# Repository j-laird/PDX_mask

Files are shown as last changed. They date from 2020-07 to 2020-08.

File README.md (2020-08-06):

# PDX Refillable Mask Cartridge Project

## Disclaimer
Home-made respirator cartridges have plenty of safety concerns.  From the design - to materials used - to workmanship when re-assembling, there are risks to using this and other designs.  If you can find commercially built cartridges, please use them instead.  If you need to experiment?  Read on.  Not my pig, not my farm.

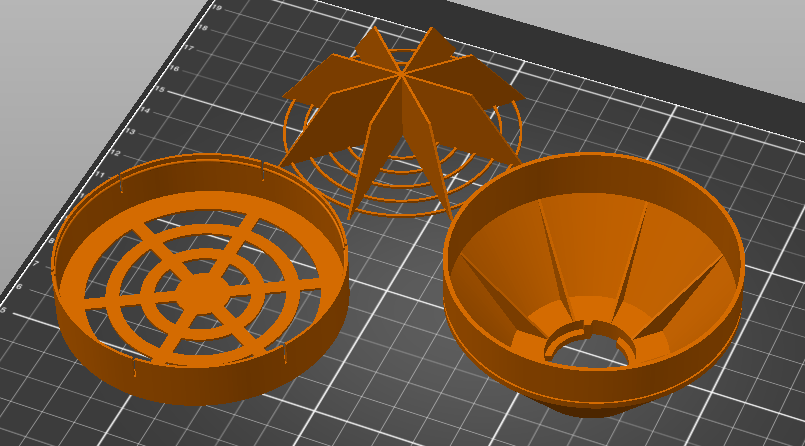
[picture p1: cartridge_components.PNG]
components


## Design Philosophy
- Not about me - my name is on it for questions, but if you can improve, please do.  
- Print Efficiency: Getting the most cartridges out to those in need is a priority
- Printability: This idea works only if different people with different printers can scale production
- Customization: OpenSCAD allows people to use free software to tweak design (improve print quality - account for variation in printer accuracy, etc)
- STLs for the People: Hopefully the default parameters make usable parts for most printers without having to load/edit design files

## Construction
Prototypes have been printed on a Prusa i3mk3 printer using PETG filament.  The design was optimized for print time, and takes advantage of the flexibility and durability of this material to snap together.  Total print time at 0.3mm layer height / draft quality is about 1h 45m per cartridge.  However:

- Cap and support can be printed at 0.3mm for speed
- Base prints good at 0.3mm now, but if you have poor surface, try 0.2mm. 

*new in v2 and later - cap has cap_fit_factor to grow/shrink for best fit.  

The design is implemented in 3 parts to provide better print quality with short print times.  A printed support is placed inside the bayonet base.  The user-side filter material will probably be cut and glued around the periphery, and the space is designed to support the use of activated carbon granules.  A second layer (environment side) can be glued to either the inside of the snap-on cap, or somehow glued to the top of the base.  Feedback welcome.

The height of the media (carbon) area is also parameteric if more/less is desired. 

## Customizing
Design implemented in OpenSCAD - Put all files in the same folder - most customization is in PDX_mask_dimensions.scad so that changes propogate to any affected parts.  

## Credits
Design leaned heavily on OpenSCAD 3M Bayonet adapter by james_lan: https://www.thingiverse.com/thing:4246959

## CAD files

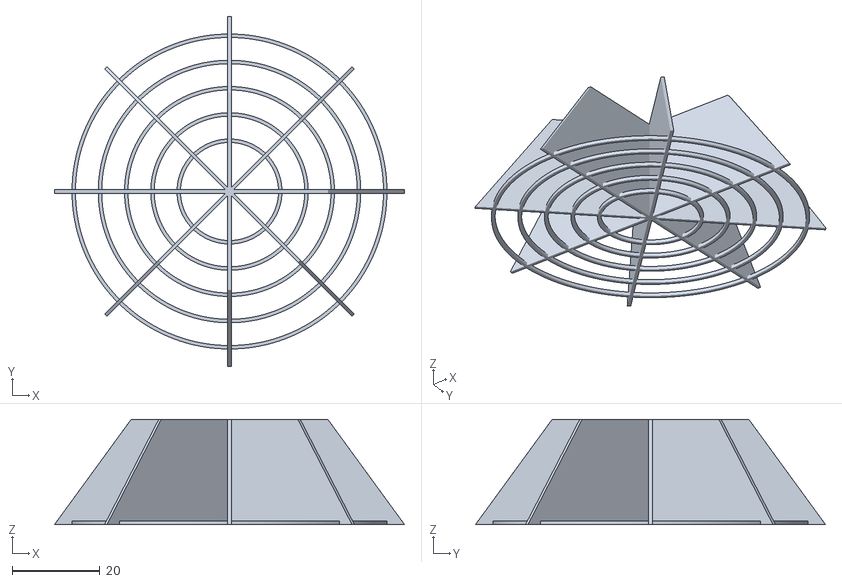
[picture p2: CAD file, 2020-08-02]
PDX_mask_support.stl
80.0 x 80.0 x 24.0

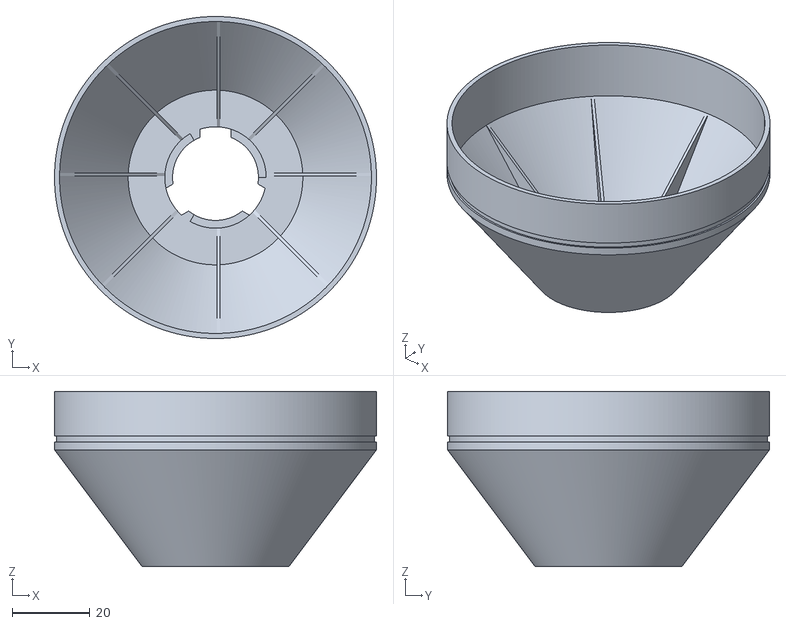
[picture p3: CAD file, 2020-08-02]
PDX_mask_base.stl
82.6 x 82.6 x 45.0

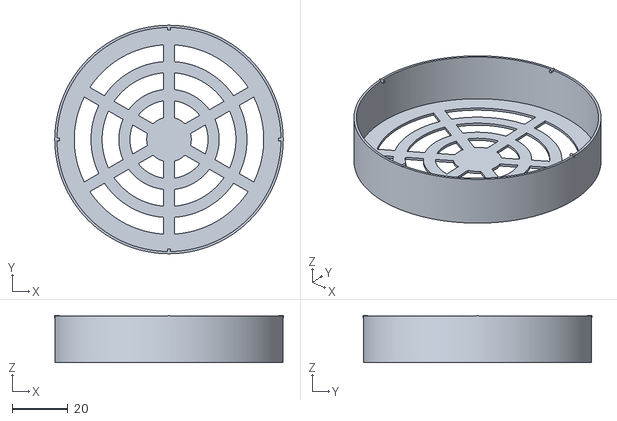
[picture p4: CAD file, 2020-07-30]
PDX_mask_cap.stl
82.2 x 82.2 x 17.0

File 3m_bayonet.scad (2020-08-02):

// source of this is https://www.thingiverse.com/thing:4246959
// with minor tweaks by @jesselaird

tolerance=0.5;
attachment_od=36;
attachment_height=6;
bayonet_od=21.5+tolerance;
bayonet_extra=2; //radius
bayonet_under=2.25;
bayonet_width=8;
bayonet_height=attachment_height-bayonet_under;
$fn=200;

module 3m_attachment() {
difference(){
	cylinder(r=attachment_od/2, h=attachment_height);
	cylinder(r=bayonet_od/2, h=attachment_height+2);
	for(i=[0:2]){
		rotate([0,0,120*i]){
            intersection(){
                cylinder(r=bayonet_od/2+bayonet_extra, h=attachment_height);
                translate([-bayonet_width/2, 0,0])
                cube([bayonet_width, attachment_od, attachment_height]);
            }
            translate([0,0,bayonet_under]) {
                intersection(){
                    cylinder(r=bayonet_od/2+bayonet_extra, h=bayonet_height);
                    translate([-bayonet_width/2, 0,0])
                    cube([bayonet_width*4, attachment_od, attachment_height]);
                }
            }
        }
	}
}
}

//To use:
// Put in same folder as 3m_bayonet.scad and in your file: 
//use <3m_bayonet.scad>
//3m_attachment();

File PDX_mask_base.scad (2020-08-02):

// PDX mask project base
// initial by Jesse Laird
// github j-laird; twitter @jesselaird

include <3m_bayonet.scad>
include <PDX_mask_dimensions.scad>

base_mount_inner_radius = attachment_od/2;
base_mount_outer_radius = base_mount_inner_radius + base_wall_thickness;
base_fin_width = 0.8;
base_rib_corner_radius = ((base_filter_inner_radius - base_mount_inner_radius) * 
                    (attachment_height / base_cone_height)
                    + base_mount_inner_radius + 0.1);

union(){
    // bayonet mount 
    3m_attachment();
    // cone transition between mount base and filter
    difference(){
        cylinder(h=base_cone_height,
                 r1=base_mount_outer_radius, 
                 r2=base_filter_outer_radius);
        cylinder(h=base_cone_height,
                 r1=base_mount_inner_radius, 
                 r2=base_filter_inner_radius);
    }
    // support between mount and cone:
    difference(){
        // Had to add fudge factor 0.1 to calculation to keep base manifold -JL
        cylinder(h=attachment_height,
                 r1=base_mount_inner_radius,
                 r2=base_rib_corner_radius);
        cylinder(h=attachment_height,
                 r=base_mount_inner_radius);
    }
    // interior ribs for reinforcement:
    difference(){
        intersection(){
            cylinder(h=base_cone_height,
                     r1=base_mount_inner_radius,
                     r2=base_filter_inner_radius);
            for(rot_deg = [0:45:135]){
                rotate([0,0,rot_deg]){
                    translate([base_fin_width/2, 
                               -1 * base_filter_inner_radius,
                               attachment_height]){
                        cube([base_fin_width, 
                              base_filter_inner_radius * 2, 
                              base_cone_height - attachment_height]);
                    }
                }
            }
        }
        translate([0,0,attachment_height]){
            cylinder(h=base_cone_height - attachment_height,
                     r1 = bayonet_od/2 + bayonet_extra,
                     r2 = base_filter_inner_radius);
        }
    }
    // filter area:
    translate([0,0,30]){
        difference(){
            // basic hollow cylinder:
            cylinder(h=base_filter_height,r=base_filter_outer_radius);
            cylinder(h=base_filter_height,r=base_filter_inner_radius);
            // now we'll remove a grove on the outside, 2mm up from where cone meets the filter area
            // - this forms a retention grove that interlocks a feature on the cap
            translate([0,0,retention_groove_offset]){
                difference(){
                    cylinder(h=retention_groove_height,
                             r=base_filter_outer_radius);
                    cylinder(h=retention_groove_height,
                             r=base_filter_outer_radius - retention_groove_depth); 
                }
            }
        }
    }
}

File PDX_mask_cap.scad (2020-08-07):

// PDX mask project - vent cap
// initial by Jesse Laird
// github j-laird; twitter @jesselaird

include <PDX_mask_dimensions.scad>

cap_inner_radius = cap_fit_factor * base_filter_outer_radius;
cap_outer_radius = cap_inner_radius + cap_wall_thickness;
cap_height_total_inner = base_filter_height;
cap_height_total_outer = base_filter_height + cap_thickness;

module cap_vent(){
    difference(){
        //circular vent features:
        union(){
            for(i=[2*cap_vent_thickness:5*cap_vent_thickness:cap_inner_radius]){
                difference(){
                    cylinder(h=cap_thickness*1.1, r=i);
                    cylinder(h=cap_thickness*1.2, r=i-3*cap_vent_thickness);
                }
            }
        }
        // support ribs for circular vent:
        union(){
            for(rot_deg=[0:60:120]){
                rotate([0,0,rot_deg]){
                    translate([0,0,cap_thickness/2]){
                        cube([2*cap_vent_thickness,2*cap_inner_radius,cap_thickness],center=true);
                    }
                }
            }
        }
    }
}

module blank_cap(){
    union(){
        // basic cap body
        difference(){
            cylinder(h=cap_height_total_outer,r=cap_outer_radius);
            translate([0,0,cap_thickness]){
                cylinder(h=cap_height_total_inner,r=cap_inner_radius);
            }
        }
        // add in retaining grove
        translate([0,0,cap_height_total_outer - retention_bump_offset]){
            rotate_extrude(){
                translate([base_filter_outer_radius + (retention_bump_depth/4),0,0]){
                    circle(r=retention_bump_depth);
                }
            }
        }
    }
}

module cap_relief_slots(){
    translate([0,0,cap_thickness+cap_height_total_inner]){
        // support ribs for circular vent:
        union(){
            for(rot_deg=[0:60:120]){
                rotate([0,0,rot_deg]){
                    translate([0,0,cap_thickness/2 + -1*cap_height_total_inner/2]){
                        rotate([90,0,0]){
                            cylinder(r=cap_wall_thickness,h=2*cap_outer_radius,center=true);
                        }
                    }
                    cube([cap_wall_thickness,
                          2*cap_outer_radius,
                          cap_height_total_inner],
                          center=true);
                    
                }
            }
        }
    }
}

union(){
    // main cap body with vents removed:
    difference(){
        blank_cap();
        cap_vent();
        cap_relief_slots();
    }
}

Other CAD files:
PDX_mask_dimensions.scad
PDX_mask_support.scad

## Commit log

2020-07-28 Update README.md
    Added credit to James Ian's OpenSCAD bayonet mount (used, modified.)
2020-07-28 Initial commit of OpenSCAD and STL files
    [3m_bayonet.scad, PDX_mask_base.scad, PDX_mask_base.stl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]
2020-07-30 Second version
    Updates to improve printability and durability including relocating cone attachment point, adding interior support ribs, and widening the bayonet/gasket interface
    [3m_bayonet.scad, PDX_mask_base.scad, PDX_mask_base.stl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]
2020-08-02 Design improvements from Hefty
    increased bayonet insert slot length because on some printers, the fitment was too close. Added retaining grove to base and producing rib around inside of cap. Segmented cap to help the rib snap into grove. Increased filter area slightly so that the filter itself is 80mm, not the outside of the filter base. My mistake.
    [3m_bayonet.scad, PDX_mask_base.scad, PDX_mask_base.stl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]
2020-08-07 Circular relief on cap slots
    Minor improvement to cap - circular strain relief at end of slots on cap to prevent cracking. Maintains fit with v3 variants of support and body.
    [PDX_mask_cap.scad]
